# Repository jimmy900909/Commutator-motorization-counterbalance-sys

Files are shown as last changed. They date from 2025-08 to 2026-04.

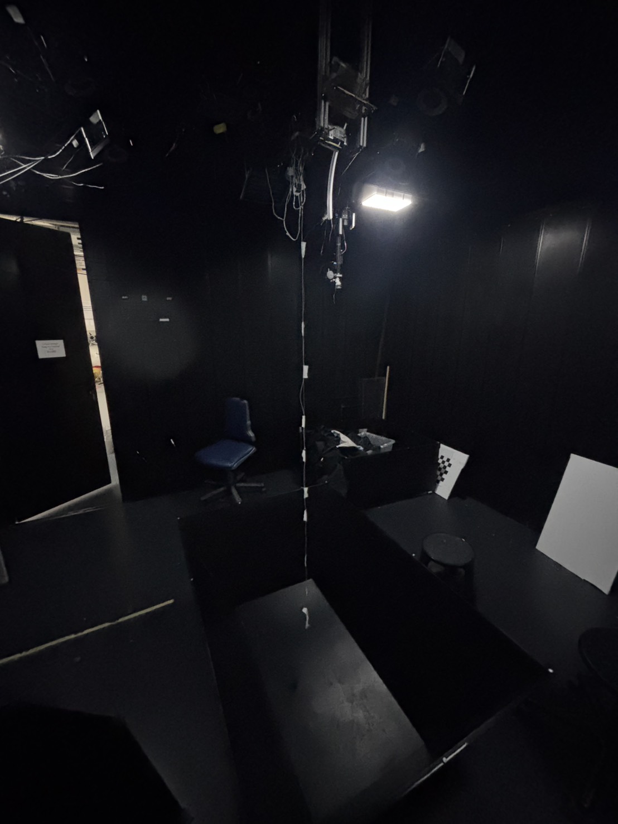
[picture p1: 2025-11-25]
images/S__6602755.jpg

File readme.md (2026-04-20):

# Active Counterbalance System for Freely-Moving Electrophysiology  
### Real-time Tension Stabilization + 3D Printed Mechanical System + Closed-Loop Firmware
Author:Wei Ching Ling

This repository contains the code, mechanical design files, and system description for an **active counterbalance system** combined with **customized torque-free commutator** that stabilizes tether tension and prevents entangle during freely-moving electrophysiology experiments.  
This system is based on the engineering framework from my master thesis, but **this implementation uses a different commutator model** and a reorganized folder structure.

to use the system, check the manual for the guide
---

https://github.com/user-attachments/assets/3104b9ad-547f-40e5-a1b2-401eba12acd4

## 📌 Project Overview

Tethered electrophysiology often suffers from:
- Mechanical noise from cable tension/torque  
- Slack formation causing entanglement  
- Excessive pulling that may damage the headstage  
- Behavioral interference in freely moving animals  

This project implements an **active counterbalance system** that:
- Measures real-time tension via load cell  
- Runs an event-driven control algorithm (retraction/payout)  
- Uses a motorized pulley to collect and release cable to maintain tension in a safe window  
- Uses 3D printed mechanical components for compact integration  
- Supports different commutator (this version uses: **customized 52 channels slip ring commutator**)  
- Provides reproducible, tunable closed-loop control logic
---



## material:
motorization:
- Stepping Motor * 1 (17HS4401)
- A4988 Motor driver
- capacitor 470muF * 1 and 1000muF * 1
- arduino nano * 1 

counterbalance:
- N20 Gearmotor with encoder (100-200RPM) 144 is used in this testing
- DRV8833 motor driver
- arduino nano* 1 or ESP 32 * 1
circuit

## 🗂 Repository Structure
- project-root/
- ├── code/
- │ └── counterblance
- │    └── /nano_version/auto1/ # Main firmware and scripts for nano
- │    └──/esp_version/auto_esp/ # Main firmware and scripts for esp
- │
- │ 
- ├── parts/ #stl. and solidworks model
- │   ├── motorisation/ # model for commutator motorization
- │   └── counterbalance/ # parts and platform for counterbalance system 
- └── README.md

The counterbalance system converts cable tension into a measurable compression force using a **pulley-mediated force-redirection mechanism**.  
The controller:
1. Reads tension (80 Hz)
2. Applies dual-EMA filtering  
3. Detects events (slack, over-tension, impact)
4. Controls motor payout/retraction  
5. Maintains tension in a safe range  

Hardware Design: The structure was printed by Prusa 3DPrinter, for motortization part, the gear set are driven by the step motor, fix the motor on the square space on the side and insert the shaft into the z14 gear to motorization the rotation of the commutator.

for the counterbalance sys, install the circuit above on to the platform at the bottom. can also check  https://github.com/jimmy900909/Commutator-counterbalance-sys-of-openEphys-coaxial-torque-free-commutator for more detail of the platform. Insert the gear motor to the space and connect the pully on as the side retract and release the thread.



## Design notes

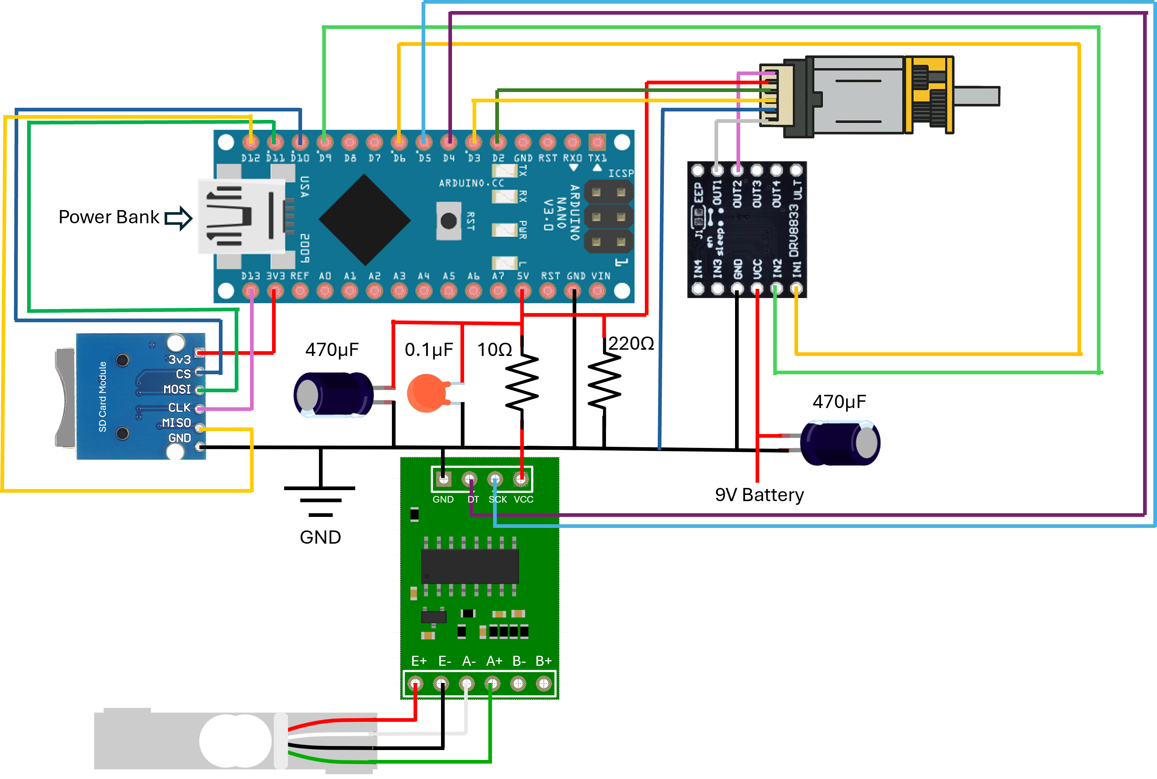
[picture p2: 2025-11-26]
docs/circuit.png

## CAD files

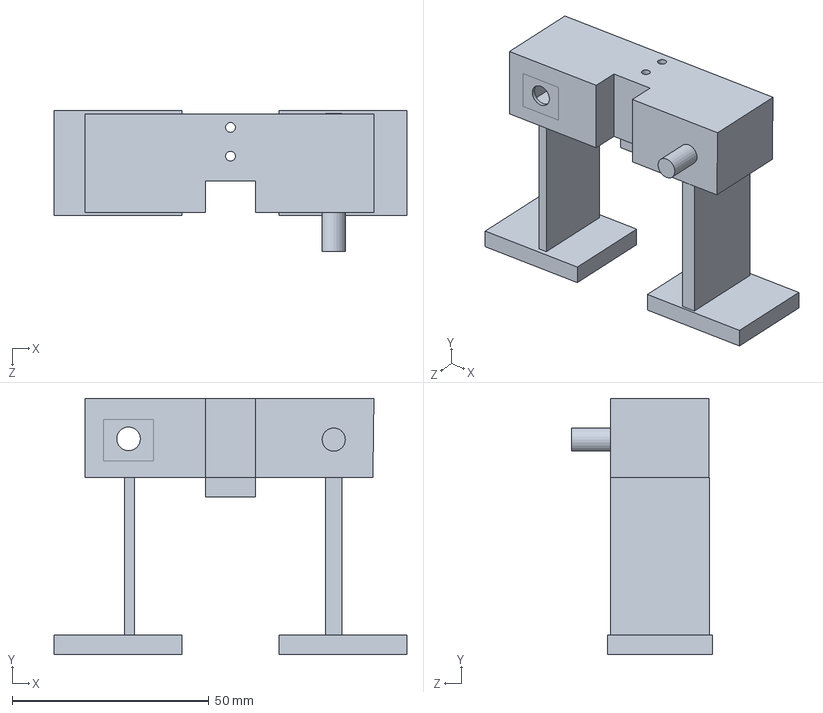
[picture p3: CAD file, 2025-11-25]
parts/counterbalance/testing/TESTING frame.SLDPRT
89.6 x 65.0 x 35.9 mm

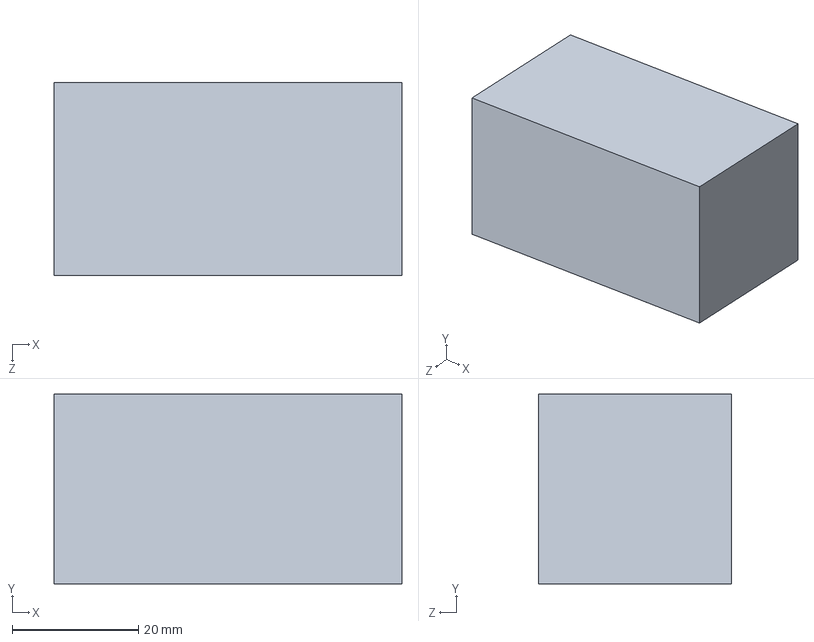
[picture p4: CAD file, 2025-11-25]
parts/counterbalance/Ver1/powerbank_holder.SLDPRT
55.1 x 30.0 x 30.5 mm

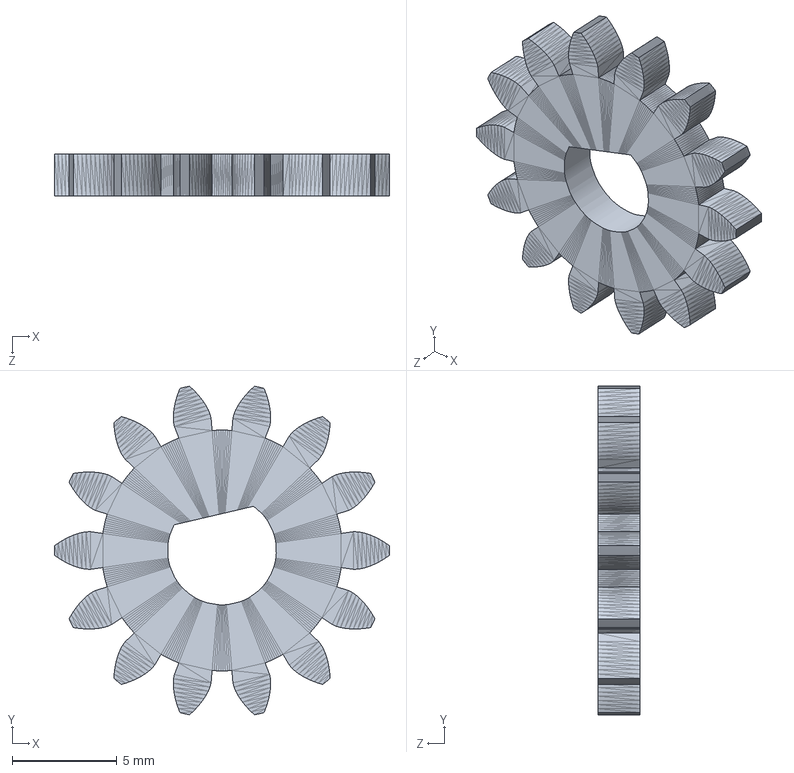
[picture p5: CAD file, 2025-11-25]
parts/motorization/gearset/Spur_M1_Pa25_Z14.SLDPRT
16.0 x 15.7 x 2.00 mm

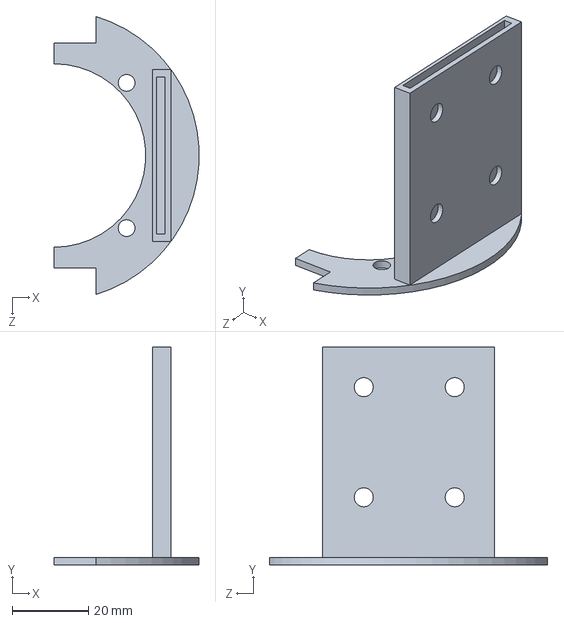
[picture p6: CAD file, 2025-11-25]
parts/motorization/maghold.SLDPRT
37.9 x 57.0 x 72.7 mm

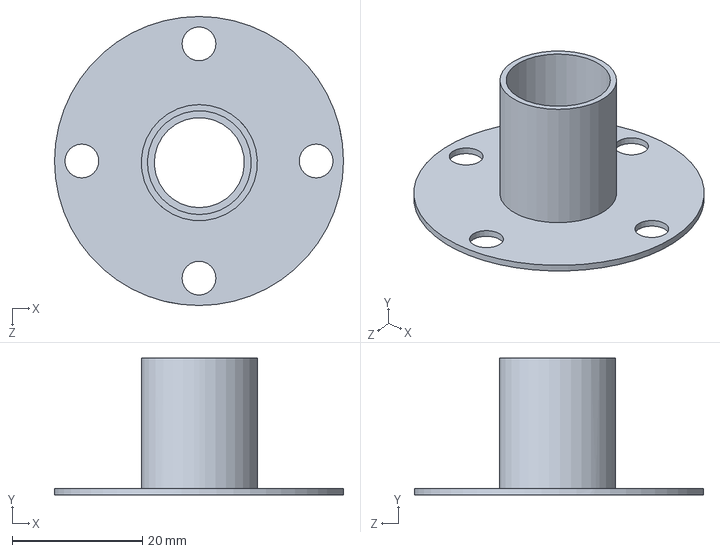
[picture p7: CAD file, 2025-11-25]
parts/motorization/Part/connector2.SLDPRT
44.4 x 21.0 x 44.4 mm

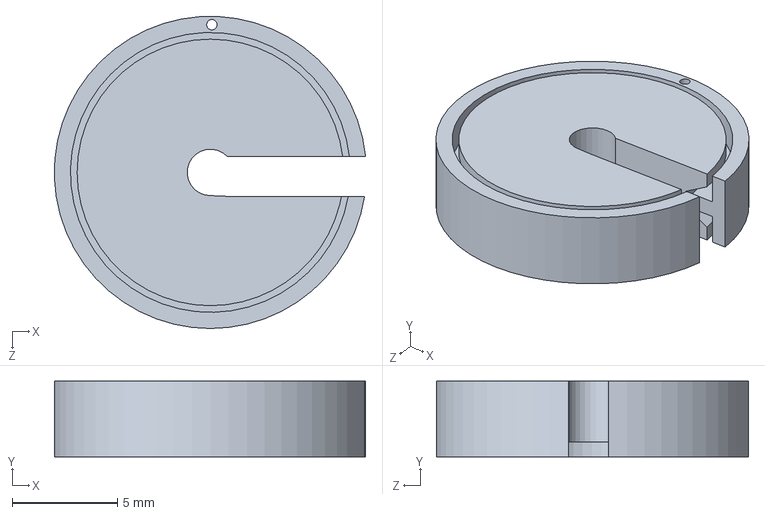
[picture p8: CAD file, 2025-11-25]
parts/counterbalance/testing/bearing.SLDPRT
14.8 x 3.60 x 14.8 mm

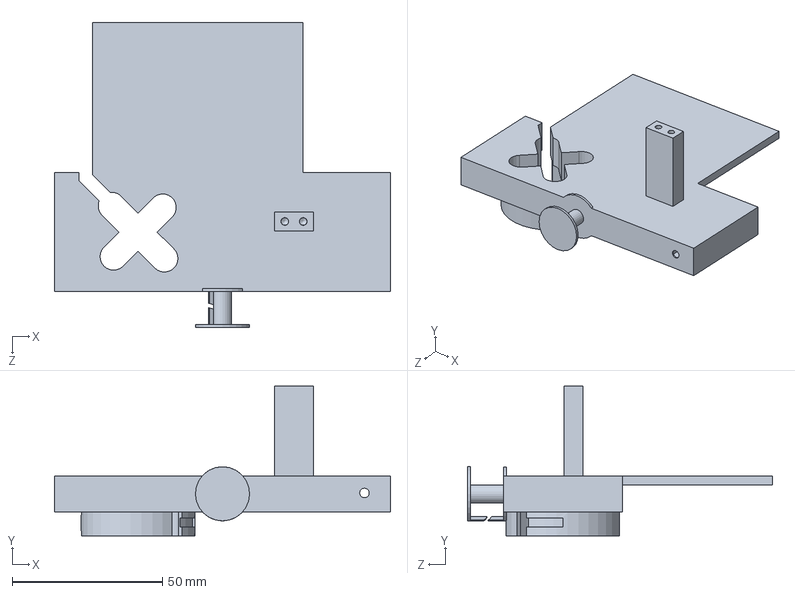
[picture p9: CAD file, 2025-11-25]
parts/counterbalance/Ver1/downconnect1.SLDPRT
111.7 x 49.8 x 101.5 mm

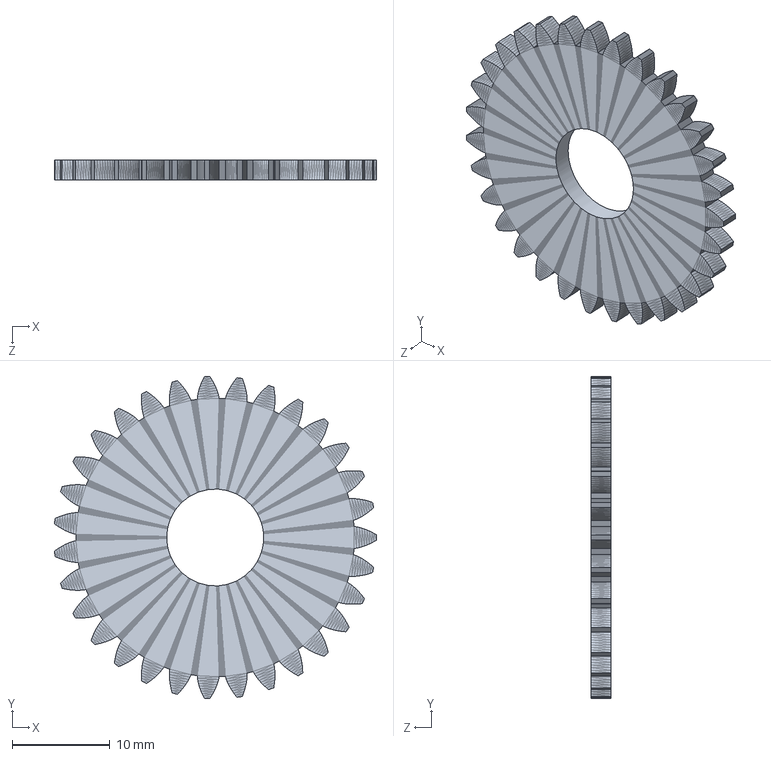
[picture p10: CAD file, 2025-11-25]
parts/motorization/gearset/Spur_M1_Pa25_Z31.SLDPRT
32.9 x 33.0 x 2.00 mm

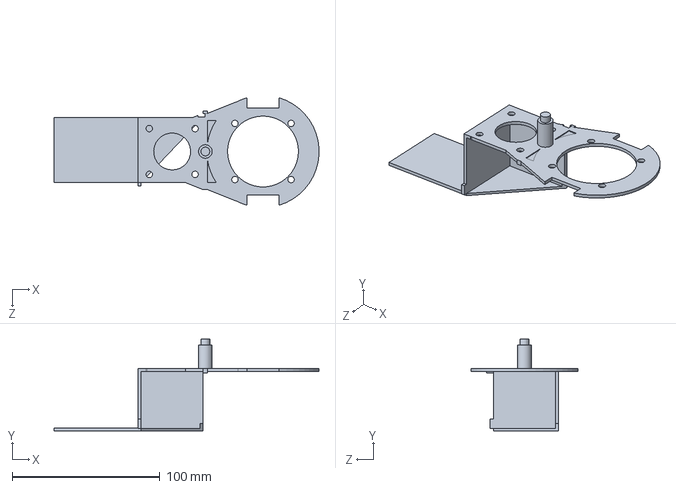
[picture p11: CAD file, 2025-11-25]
parts/motorization/holder.SLDPRT
179.4 x 62.0 x 72.7 mm

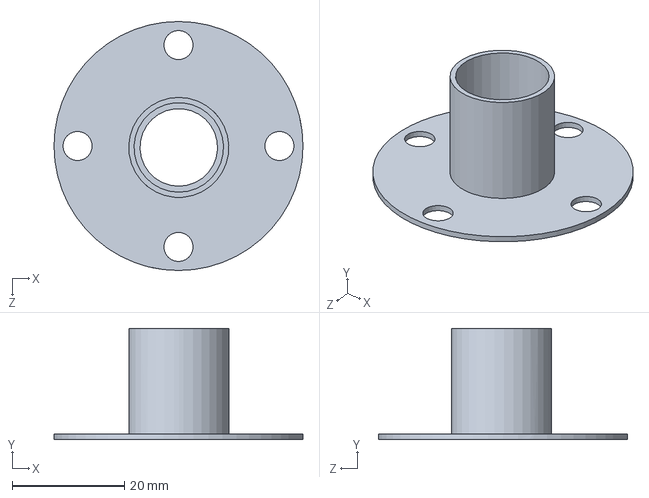
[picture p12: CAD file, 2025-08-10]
parts/motorization/Part/GEARbase.SLDPRT
44.4 x 19.9 x 44.4 mm

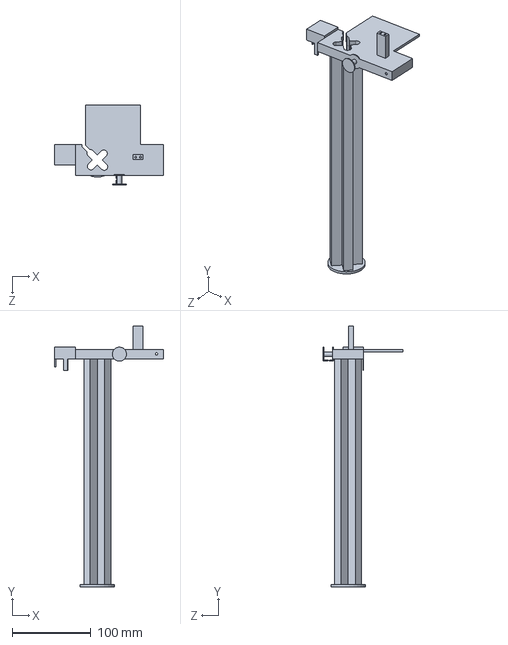
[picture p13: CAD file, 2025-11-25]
parts/counterbalance/Ver1/downconnect.SLDPRT
138.2 x 331.8 x 101.5 mm

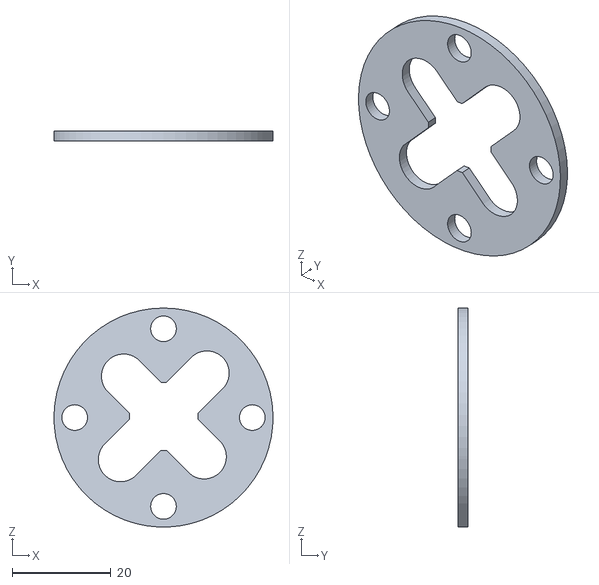
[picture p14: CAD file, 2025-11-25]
parts/motorization/attachplatform.STL
44.4 x 2.00 x 44.4

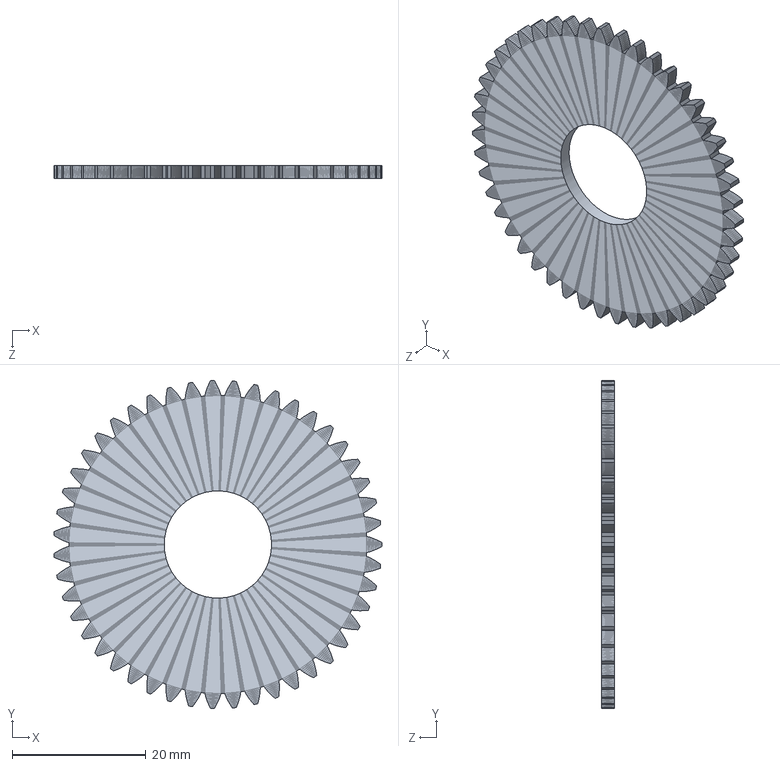
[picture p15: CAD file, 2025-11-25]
parts/motorization/gearset/Spur_M1_Pa25_Z47.SLDPRT
49.0 x 49.0 x 2.00 mm

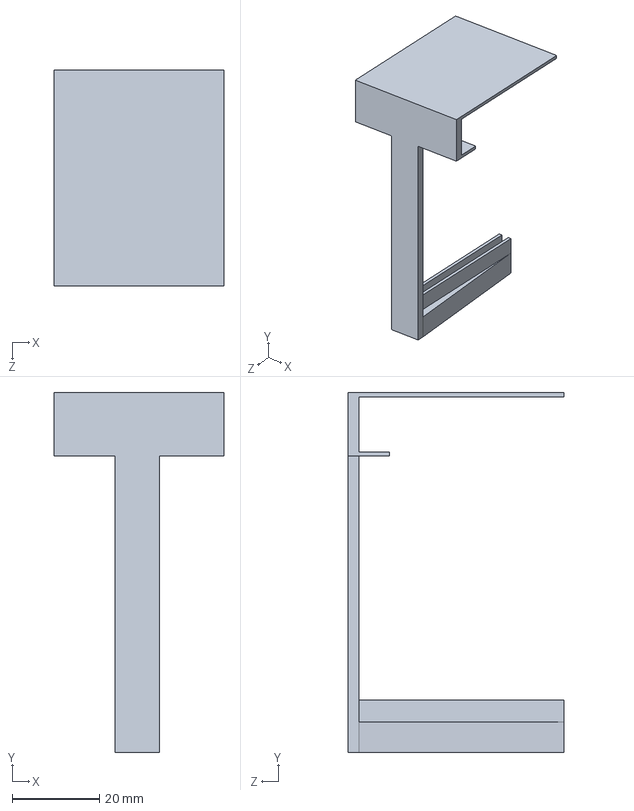
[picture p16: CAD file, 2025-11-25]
parts/counterbalance/Ver1/pcb_holder.SLDPRT
39.0 x 82.6 x 49.5 mm

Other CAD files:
parts/motorization/magholder2.SLDPRT
parts/counterbalance/Ver1/batteryholder.SLDPRT
parts/motorization/magholder..SLDPRT
parts/counterbalance/Ver1/downconnectube.STL
parts/counterbalance/Ver1/HOLDERpcb.STL
parts/counterbalance/Ver1/batteryholder.STL
parts/counterbalance/Ver1/connector.SLDPRT
parts/counterbalance/Ver1/connector.STL
parts/counterbalance/Ver1/downconnect1.STL
parts/counterbalance/Ver1/downconnect2.STL
parts/counterbalance/Ver1/powerbank_holder.STL
parts/counterbalance/Ver1/pulley_fixed.SLDPRT
parts/counterbalance/Ver1/pulley_fixed.STL
parts/counterbalance/Ver1/pulley_motor.SLDPRT
parts/counterbalance/Ver1/pulley_motor.STL
parts/counterbalance/Ver1/零件1.SLDPRT
parts/counterbalance/testing/TESTING frame.STL
parts/counterbalance/testing/bearing.STL
parts/motorization/Spur_M1_Pa25_Z14.STL
parts/motorization/Spur_M1_Pa25_Z31.STL
parts/motorization/combine_lifted.SLDPRT
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

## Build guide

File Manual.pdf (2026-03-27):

## User Guide for Sinaps Counterbalance sys

Rotation System and tension control

The commutation should rotate the same direction as target’s rotation(Rat) whenever the degree difference accumulates to 90 degrees.

1. Connection check

There are 3 connection on PCB board

-USB port between PC and Arduino nano

-Motor power

-Motor and driver(A4988)

Ensure they are all connected.

2. Software check
1. Turn on cameras and Motive
2. Create rigidbody and set streaming ID
3. Enable streaming
4. Open motivetracking.py
(under Desktop/NatnetSDK/Samples/pythonclient/)
5. Run the code, if the connection works, it will show port detected.
Should show:
busy=yes, Δyaw={delta_yaw:+.2f}°, accumulation={accum_angle:+.2f}°"

Common Question:

1. All plugs are connected and you hear that motor is moving but not rotation correctly- check the connection of the motor and driver, the 4 pins might be inverse.

Counterbalance system

This closed loop system is independent of the rotation system.

1. Check hardware connection
1. battery for motor (DO NOT attach inversely GND and 9V) the LED on DRV8833 should turn on
2. plug on the headstage to animal
3. Pull the thread to make it not lean on the load cell

4.. plug on the power of the Arduino nano

5. release the thread

To know,

1. highly recommend to go through the process without animal first

### 2. Once the two power connections are plugged, the sys will start to work in

closed-loop, please do the safety check on connection to the animal first
3. the parameters need to be adjust depend on the weight of the cable and where it attach

Parameter for counterbalance system:

In file /code/counterbalce/auto.ino, you can play with the parameter for customized env.

Sensor parameters:

Line 71-72

Lower limit- Increase if the wire is too loose but sys didn’t retract

-Decrease if the wire is already tight but still retracting

Upper limit-Increase if the sys is too sensitive to the jittering

-Decrease if feel too strong resistance when pulling

Motor parameters:

Retracting :

Line 161- Deadzone :The minimum PWM that can drive the motor

Line 37-40-speed of the retracting

Releasing:

43- Base_payout: minimum speed when the tension cross the boarder(upper_threshold)

44- Maxpayout: this is the key that should be control. If the sys release to fast in a very short period, the wire will be over released and too long that will cause entangle.

48.Burst_payout: when the tension increase sharply, the speed of the payout, is constrained by 44.

Recommended numbers for sinaps.

Line/numbers

71/72:14.8/32.5 (can adjust in the step of 0.5g)

161:70

43:70

44:110 or 120

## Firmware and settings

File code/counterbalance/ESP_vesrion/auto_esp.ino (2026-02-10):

#include <Arduino.h>
#include <math.h>
#include <stdlib.h>
#include "HX711.h"

// ===================== Pin map (ESP32) =====================
// HX711
#define DOUT 34
#define CLK  25

// DRV8833
#define AIN1 26
#define AIN2 27

// Encoder
#define ENCODER_A 32
#define ENCODER_B 33

// ===================== HX711 =====================
HX711 scale;
float calibration_factor = 7180;  // g
const float HX_RATE_HZ = 80.0f;

// ===================== Encoder → v_line =====================
const float COUNTS_PER_METER = 11357.0f;
volatile long encoderCount = 0;    // ISR writes
static portMUX_TYPE encMux = portMUX_INITIALIZER_UNLOCKED;

long lastCount = 0;
uint32_t lastEncMs = 0;
float v_line = 0.0f;
float leash_len_m = 0.0f;

// ===================== Motor / PWM =====================
const int remotorSpeed = 65;   // retract PWM (upper bound)
int pwm_state = 0;

const int PWM_STEP_OUT = 80;
const int PWM_STEP_IN  = 30;

// retracting PWM
const int   BASE_RETRACT_PWM     = 35;
const int   MAX_RETRACT_PWM      = 60;
const int   MIN_RETRACT_PWM      = 40;
const float KP_RETRACT_PWM_PER_G = 3.0f;

// loosening PWM
const int   BASE_PAYOUT_PWM   = 50;
const int   MAX_PAYOUT_PWM    = 110;
const float KP_PWM_PER_G      = 4.0f;

// Burst（instant payout for strong drag）
const int BURST_PWM = 100;
const unsigned long BURST_MS = 50;
unsigned long burst_until_ms = 0;

// Landing impact give-way
const float IMPACT_DTDT_GPS = 90.0f;
const float IMPACT_NEAR_UPPER_G = 0.8f;
const unsigned long IMPACT_COAST_MS = 120;
const int IMPACT_PAYOUT_PWM = 70;
unsigned long impact_until_ms = 0;

// No instanst retracting after burst
const unsigned long POST_BURST_NO_RETRACT_MS = 600;
unsigned long no_retract_until_ms = 0;

// Smooth tension (EMA)
const float T_ALPHA_FAST = 0.5f;
const float T_ALPHA_SLOW = 0.3f;

// threshold
float lower_limit = 16.3f;
float upper_limit = 37.5f;

float V_OUT_MIN = 0.004f;
float T_MARGIN_G = 0.7f;
unsigned long ALLOW_PAYOUT_CONFIRM_MS = 5;
bool allow_payout_latch = false;
unsigned long allow_payout_since_ms = 0;

// locked fast path
const float V_EPS_LOCKED   = 0.003f;
const float T_LOCK_MARGING = 3.0f;
const float DTDT_LOCK_GPS  = 55.0f;
const unsigned long LOCK_CONFIRM_MS = 12;
bool locked_latch = false;
unsigned long locked_since_ms = 0;

// dT/dt smoothing
const float DTDTA = 0.25f;

// Active-Coast near upper limit
const int ASSIST_PWM = 80;

// Anti-chatter / Grace
bool inRetract = false;
unsigned long retract_start_ms = 0;
long          retract_start_cnt = 0;

const unsigned long MIN_RETRACT_MS  = 50;
const long          MIN_RETRACT_CNT = 10;

const unsigned long LOOSEN_GRACE_MS = 900;
unsigned long loosen_grace_until_ms = 0;

const float LOWER_HYST_G = 0.8f;

// ===================== ESP32 LEDC PWM =====================
static const int PWM_FREQ = 20000;   // 20 kHz
static const int PWM_RES  = 8;       // 8-bit 0..255
static const int CH_AIN1  = 0;
static const int CH_AIN2  = 1;

// ===================== FreeRTOS shared (HX711 -> Control/Log) =====================
struct TensionMsg {
  uint32_t ms;
  float raw;
  float T_fast;
  float T_slow;
  float dTdt_gps;
};

static QueueHandle_t qTension = nullptr;
static TaskHandle_t hxTaskHandle = nullptr;
static TaskHandle_t ctrlTaskHandle = nullptr;
static TaskHandle_t logTaskHandle = nullptr;

// ===================== helpers =====================
inline void motorCoast() {
  ledcWrite(CH_AIN1, 0);
  ledcWrite(CH_AIN2, 0);
}

void driveMotor(int pwmSigned) {
  if (pwmSigned == 0) { motorCoast(); return; }

  if (pwmSigned > 0) { // retract
    int pwm = constrain(pwmSigned, 0, 255);
    ledcWrite(CH_AIN1, 0);
    ledcWrite(CH_AIN2, pwm);
  } else { // payout
    int pwm = constrain(-pwmSigned, 0, 255);
    ledcWrite(CH_AIN1, pwm);
    ledcWrite(CH_AIN2, 0);
  }
}

int slewPWM(int target) {
  if (target == pwm_state) return pwm_state;

  if ((target > 0 && pwm_state >= 0) || (target < 0 && pwm_state <= 0)) {
    int step = (target > 0) ? PWM_STEP_IN : PWM_STEP_OUT;
    if (target > pwm_state) pwm_state = min(pwm_state + step, target);
    else                    pwm_state = max(pwm_state - step, target);
  } else {
    int step = (pwm_state > 0) ? PWM_STEP_IN : PWM_STEP_OUT;
    if (pwm_state > 0) pwm_state = max(0, pwm_state - step);
    else               pwm_state = min(0, pwm_state + step);
  }
  return pwm_state;
}

int map_constrain_float(float x, float in_min, float in_max, int out_min, int out_max) {
  if (in_max - in_min == 0) return out_min;
  float t = (x - in_min) / (in_max - in_min);
  if (t < 0) t = 0;
  if (t > 1) t = 1;
  float y = out_min + t * (out_max - out_min);
  return (int)y;
}

int applyDeadzone(int pwmSigned) {
  const int DEADZONE = 70;
  if (pwmSigned == 0) return 0;
  if (pwmSigned > 0) return max(pwmSigned, DEADZONE);
  return min(pwmSigned, -DEADZONE);
}

// ===================== ISR =====================
void IRAM_ATTR encoderISR() {
  int a = digitalRead(ENCODER_A);
  int b = digitalRead(ENCODER_B);
  portENTER_CRITICAL_ISR(&encMux);
  if (a == b) encoderCount++;
  else        encoderCount--;
  portEXIT_CRITICAL_ISR(&encMux);
}

// ===================== Task: HX711 80Hz =====================
void taskHX711(void *pv) {
  const TickType_t period = pdMS_TO_TICKS(1000 / 80); // ~12 ms
  TickType_t lastWake = xTaskGetTickCount();

  float T_fast_g = 0.0f;
  float T_slow_g = 0.0f;

  float dTdt_gps = 0.0f;
  float T_prev_for_dt = 0.0f;
  bool have_prev_T = false;
  uint32_t last_hx_ms = millis();

  for (;;) {
    vTaskDelayUntil(&lastWake, period);

    if (!scale.is_ready()) continue;

    float raw = scale.get_units(1);

    // EMA
    T_fast_g = T_fast_g + T_ALPHA_FAST * (raw - T_fast_g);
    T_slow_g = T_slow_g + T_ALPHA_SLOW * (raw - T_slow_g);

    uint32_t now = millis();
    float dtT_s = max(0.001f, (now - last_hx_ms) * 1e-3f);

    float dTdt_raw = 0.0f;
    if (!have_prev_T) { dTdt_raw = 0.0f; have_prev_T = true; }
    else dTdt_raw = (T_fast_g - T_prev_for_dt) / dtT_s;

    T_prev_for_dt = T_fast_g;
    last_hx_ms = now;

    dTdt_gps = DTDTA * dTdt_raw + (1.0f - DTDTA) * dTdt_gps;

    TensionMsg msg;
    msg.ms = now;
    msg.raw = raw;
    msg.T_fast = T_fast_g;
    msg.T_slow = T_slow_g;
    msg.dTdt_gps = dTdt_gps;

    xQueueOverwrite(qTension, &msg);
  }
}

// ===================== Task: Control loop =====================
void taskControl(void *pv) {
  const TickType_t period = pdMS_TO_TICKS(1); // 1 ms
  TickType_t lastWake = xTaskGetTickCount();

  // cached tension (if queue has no update, keep last)
  TensionMsg t = {0, 0, 0, 0, 0};

  lastEncMs = millis();

  for (;;) {
    vTaskDelayUntil(&lastWake, period);

    // 1) latest tension
    TensionMsg newT;
    if (xQueueReceive(qTension, &newT, 0) == pdTRUE) t = newT;

    uint32_t now = millis();

    // 2) encoder -> v_line
    uint32_t dt_ms = now - lastEncMs;
    if (dt_ms == 0) dt_ms = 1;
    lastEncMs = now;

    long cnt;
    portENTER_CRITICAL(&encMux);
    cnt = encoderCount;
    portEXIT_CRITICAL(&encMux);

    long dcount = cnt - lastCount;
    lastCount = cnt;

    float dt = dt_ms * 1e-3f;
    v_line = (COUNTS_PER_METER > 1e-6f) ? ((float)dcount / COUNTS_PER_METER) / dt : 0.0f;
    leash_len_m += v_line * dt;

    // 3) your control logic (ported)
    float raw    = t.raw;
    float T_fast = t.T_fast;
    float T_slow = t.T_slow;
    float dTdt_gps = t.dTdt_gps;

    // ---- instant payout decision ----
    bool sudden_pull = ((raw > upper_limit + 15.0f) || (T_fast > upper_limit + 15.0f)) && (dTdt_gps > 70.0f);
    bool not_retracting = (v_line <= 0.0f);
    bool instant_payout = sudden_pull && not_retracting;

    if (instant_payout) {
      unsigned long new_until = now + BURST_MS;
      if (new_until > burst_until_ms) burst_until_ms = new_until;

      loosen_grace_until_ms = max(loosen_grace_until_ms, now + LOOSEN_GRACE_MS);
      no_retract_until_ms   = max(no_retract_until_ms,   now + POST_BURST_NO_RETRACT_MS);

      inRetract = false;

      allow_payout_latch = true;
      allow_payout_since_ms = now;
    }

    // ---- burst window ----
    if (now < burst_until_ms) {
      int steppedPWM = slewPWM(-BURST_PWM);
      steppedPWM = applyDeadzone(steppedPWM);
      driveMotor(steppedPWM);
      continue;
    }

    // ---- impact detect ----
    bool impact_detect = inRetract && ((dTdt_gps > IMPACT_DTDT_GPS) || (T_fast > upper_limit - IMPACT_NEAR_UPPER_G));
    if (impact_detect) {
      unsigned long new_until = now + IMPACT_COAST_MS;
      if (new_until > impact_until_ms) impact_until_ms = new_until;
    }

    if (now < impact_until_ms) {
      int targetPWM = 0;
      if (T_fast > upper_limit - 0.3f) {
        targetPWM = -IMPACT_PAYOUT_PWM;
      }
      int steppedPWM = slewPWM(targetPWM);
      steppedPWM = applyDeadzone(steppedPWM);
      driveMotor(steppedPWM);
      inRetract = false;
      continue;
    }

    // ---- allow payout latches ----
    bool line_out = (v_line < -V_OUT_MIN);
    (void)line_out; // kept for future use

    bool high_T = (T_fast > (upper_limit + T_MARGIN_G));
    if (high_T) {
      if (!allow_payout_latch) { allow_payout_latch = true; allow_payout_since_ms = now; }
    } else {
      allow_payout_latch = false;
    }
    bool allow_payout_dir = allow_payout_latch && (now - allow_payout_since_ms >= ALLOW_PAYOUT_CONFIRM_MS);

    bool spool_static = (fabs(v_line) < 0.003f);
    bool locked_trig  = spool_static && (T_fast > upper_limit + T_LOCK_MARGING) && (dTdt_gps > DTDT_LOCK_GPS);
    if (locked_trig) {
      if (!locked_latch) { locked_latch = true; locked_since_ms = now; }
    } else {
      locked_latch = false;
    }
    bool allow_payout_locked = locked_latch && (now - locked_since_ms >= LOCK_CONFIRM_MS);

    bool allow_payout = allow_payout_dir || allow_payout_locked;

    // ---- main targetPWM decision ----
    int targetPWM = 0;

    if (T_fast > upper_limit) {
      if (allow_payout) {
        float over_g = T_fast - upper_limit;
        int pwm = (int)(BASE_PAYOUT_PWM + KP_PWM_PER_G * over_g);
        pwm = constrain(pwm, BASE_PAYOUT_PWM, MAX_PAYOUT_PWM);
        targetPWM = -pwm;

        loosen_grace_until_ms = now + LOOSEN_GRACE_MS;
        no_retract_until_ms   = max(no_retract_until_ms, now + POST_BURST_NO_RETRACT_MS);

        inRetract = false;
      } else {
        targetPWM = 0;
      }
    } else if (T_slow < (lower_limit - LOWER_HYST_G)
               && now >= loosen_grace_until_ms
               && now >= no_retract_until_ms) {

      if (!inRetract) {
        inRetract = true;
        retract_start_ms = now;
        retract_start_cnt = cnt;
      }

      float under_g = (lower_limit - T_slow);
      int pwm = (int)(BASE_RETRACT_PWM + KP_RETRACT_PWM_PER_G * under_g);
      pwm = constrain(pwm, MIN_RETRACT_PWM, MAX_RETRACT_PWM);
      targetPWM = +pwm;

    } else if (T_fast < lower_limit) {
      targetPWM = 0;
    } else {
      if (inRetract) {
        if (T_fast > upper_limit - 0.8f) {
          targetPWM = 0;
          inRetract = false;
        } else {
          bool time_ok = (now - retract_start_ms) >= MIN_RETRACT_MS;
          bool cnt_ok  = (labs(cnt - retract_start_cnt) >= MIN_RETRACT_CNT);
          bool window_ok = (now >= loosen_grace_until_ms) && (now >= no_retract_until_ms);

          if (time_ok && cnt_ok && window_ok) {
            targetPWM = 0;
            inRetract = false;
          } else {
            int cap = map_constrain_float(T_fast,
                                          lower_limit - 1.0f,
                                          upper_limit - 0.5f,
                                          remotorSpeed,
                                          10);
            cap = constrain(cap, 10, remotorSpeed);
            targetPWM = +cap;
          }

          if (!window_ok) {
            targetPWM = 0;
            inRetract = false;
          }
        }
      } else {
        targetPWM = 0;
      }
    }

    // ---- assist payout near upper, spool static ----
    bool nearly_upper = (T_fast >= (upper_limit - 0.3f));
    if (targetPWM == 0 && nearly_upper && spool_static) {
      targetPWM = -ASSIST_PWM;
    }

    // ---- no retract windows ----
    if (now < loosen_grace_until_ms || now < no_retract_until_ms) {
      if (targetPWM > 0) targetPWM = 0;
    }

    // ---- apply slew + deadzone ----
    int steppedPWM = slewPWM(targetPWM);
    steppedPWM = applyDeadzone(steppedPWM);
    driveMotor(steppedPWM);
  }
}

// ===================== Task: Log 10Hz =====================
void taskLog(void *pv) {
  const TickType_t period = pdMS_TO_TICKS(100); // 10 Hz
  TickType_t lastWake = xTaskGetTickCount();

  TensionMsg t = {0, 0, 0, 0, 0};

  for (;;) {
    vTaskDelayUntil(&lastWake, period);

    TensionMsg newT;
    if (xQueueReceive(qTension, &newT, 0) == pdTRUE) t = newT;

    Serial.print("T_fast(g)="); Serial.print(t.T_fast, 2);
    Serial.print("  T_slow(g)="); Serial.print(t.T_slow, 2);
    Serial.print("  dTdt="); Serial.print(t.dTdt_gps, 2);
    Serial.print("  v_line(m/s)="); Serial.print(v_line, 3);
    Serial.print("  PWM="); Serial.print(pwm_state);
    Serial.print("  inRetract="); Serial.print(inRetract ? 1 : 0);
    Serial.println();
  }
}

// ===================== setup / loop =====================
void setup() {
  Serial.begin(115200);
  delay(300);

  // HX711 init
  scale.begin(DOUT, CLK);
  delay(1500);
  if (!scale.is_ready()) {
    Serial.println("HX711 not found.");
    while (1) delay(200);
  }
  scale.set_scale(calibration_factor);
  scale.tare();

  // Encoder init
  pinMode(ENCODER_A, INPUT_PULLUP);
  pinMode(ENCODER_B, INPUT_PULLUP);
  attachInterrupt(digitalPinToInterrupt(ENCODER_A), encoderISR, CHANGE);

  // LEDC init (motor PWM)
  ledcSetup(CH_AIN1, PWM_FREQ, PWM_RES);
  ledcSetup(CH_AIN2, PWM_FREQ, PWM_RES);
  ledcAttachPin(AIN1, CH_AIN1);
  ledcAttachPin(AIN2, CH_AIN2);
  motorCoast();

  // Queue: length 1 (keep latest)
  qTension = xQueueCreate(1, sizeof(TensionMsg));
  if (!qTension) {
    Serial.println("Queue create failed.");
    while (1) delay(200);
  }

  // Start tasks
  // 建議：Control pin core 1，HX711/Log core 0
  xTaskCreatePinnedToCore(taskHX711,   "hx711",  4096, nullptr, 2, &hxTaskHandle,   0);
  xTaskCreatePinnedToCore(taskControl, "ctrl",   6144, nullptr, 3, &ctrlTaskHandle, 1);
  xTaskCreatePinnedToCore(taskLog,     "log",    4096, nullptr, 1, &logTaskHandle,  0);

  Serial.println("ESP32 FreeRTOS version started.");
}

void loop() {
  // All work is in tasks.
  vTaskDelay(pdMS_TO_TICKS(1000));
}

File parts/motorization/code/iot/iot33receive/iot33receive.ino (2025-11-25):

// Nano 33 IoT Receiver: UDP "dir,steps" -> A4988 at 1/16 microstep
#include <WiFiNINA.h>
#include <WiFiUdp.h>

const char* SSID = "Jimmys";
const char* PASS = "0937333355";


WiFiUDP udp;
const uint16_t UDP_PORT = 9000;

const int DIR_PIN  = 2;
const int STEP_PIN = 3;
const int EN_PIN   = 4;

// 1/16 微步下要更快的脈衝，先給個保守值，之後可再調小加速
int STEP_US  = 300;   // 每半週期(LOW/HIGH)的延遲，數值越小越快(可試 200、150、100)

void stepN(int n){
  for(int i=0;i<n;i++){
    digitalWrite(STEP_PIN, HIGH); delayMicroseconds(STEP_US);
    digitalWrite(STEP_PIN, LOW);  delayMicroseconds(STEP_US);
  }
}

void setup() {
  Serial.begin(115200);
  pinMode(DIR_PIN, OUTPUT);
  pinMode(STEP_PIN, OUTPUT);
  pinMode(EN_PIN, OUTPUT);
  digitalWrite(EN_PIN, LOW); // 使能
  delay(3000);
  Serial.print("WiFi connecting");
  WiFi.begin(SSID, PASS);
  while (WiFi.status() != WL_CONNECTED) { delay(300); Serial.print("."); }
  Serial.println("\nWiFi connected!");
  Serial.print("Nano 33 IoT IP: "); Serial.println(WiFi.localIP());

  udp.begin(UDP_PORT);
  Serial.print("UDP listening on "); Serial.println(UDP_PORT);
  Serial.println("Remember: A4988 MS1/MS2/MS3 = HIGH for 1/16 microstep.");
}

void loop() {
  int packetSize = udp.parsePacket();
  if (!packetSize) return;

  char buf[32];
  int len = udp.read(buf, sizeof(buf)-1);
  if (len <= 0) return;
  buf[len] = '\0';

  int dir=0, steps=0;
  if (sscanf(buf, "%d,%d", &dir, &steps) == 2) {
    Serial.print("RX <- dir="); Serial.print(dir);
    Serial.print(", steps="); Serial.println(steps);

    digitalWrite(DIR_PIN, (dir > 0) ? HIGH : LOW);
    stepN(steps);
  } else {
    Serial.print("Bad packet: "); Serial.println(buf);
  }
}

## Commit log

2025-08-11 ver lifted
    [downconnect.SLDPRT, downconnect1.SLDPRT, downconnect1.STL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]
2026-01-19 Add image and update material section in README
    Added an image for motorization section and updated material list.
2026-01-19 Change image syntax for motorization section
    Updated image syntax in README for better display.
2026-02-27 Clarify microcontroller options in readme
    Updated the readme to specify the use of ESP32 as an alternative to Arduino Nano.
